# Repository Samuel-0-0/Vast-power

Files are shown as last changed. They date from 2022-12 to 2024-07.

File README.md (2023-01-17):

# Vast Power

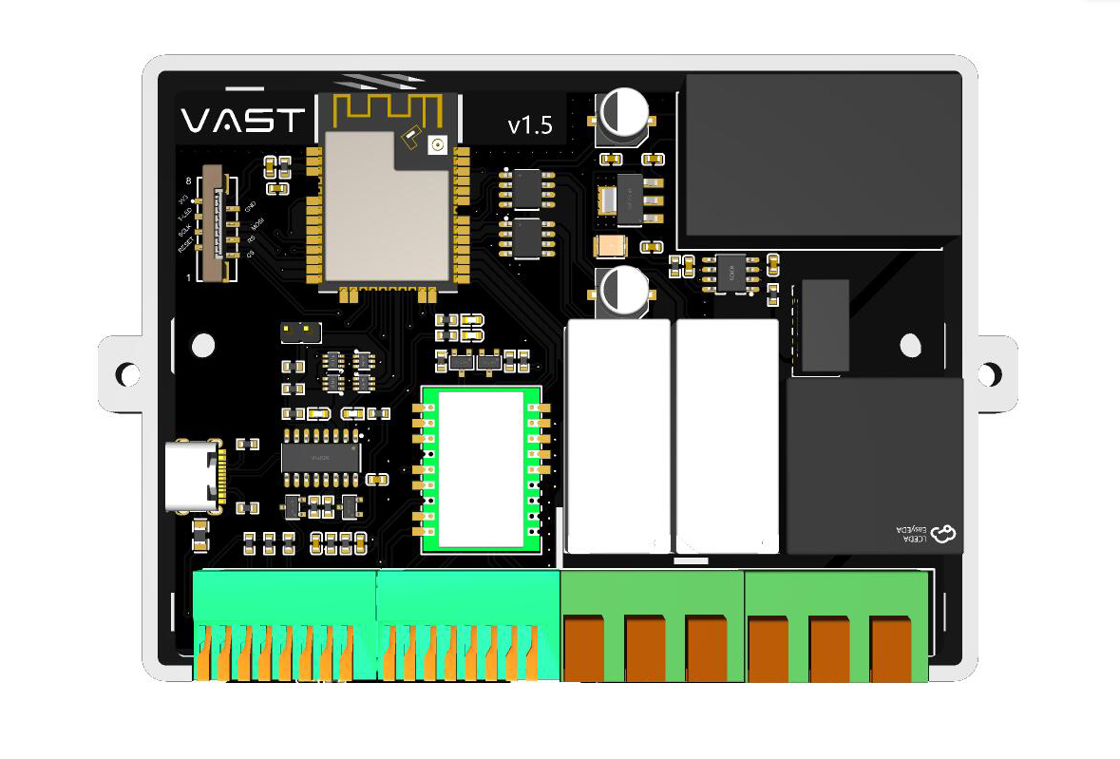
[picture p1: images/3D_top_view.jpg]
Vast-power


本项目原本是因为自己的一些需求而设计，顺便也为将来可能的项目进行前期试水。

## 主要功能

* 可与Home Assistant智能家居系统互联，实现远程控制的目的
* 离线语音控制，可直接控制灯光、继电器等
* 高精度电量统计模块，可精准统计负载耗电量
* 2路16A磁保持继电器
* RGB端口，可用于控制灯光（建议使用100珠及以上SK6812灯带）
* SPI屏幕接口，可外接显示屏自定义显示内容
  * 亦可用于扩展其他SPI设备
* 编码器接口，可外接编码器
  * 亦可拓展为3路输入输出IO（GPIO0受限使用，ESP32启动时不能为低电平）
* 2路ADC接口，或者用于2路IO输入

## 技术依赖

* ESP32程序使用[ESPHome](https://esphome.io/)构建
* 离线语音基于[智能公元](http://www.smartpi.cn/)定制的语音固件

## 接口介绍

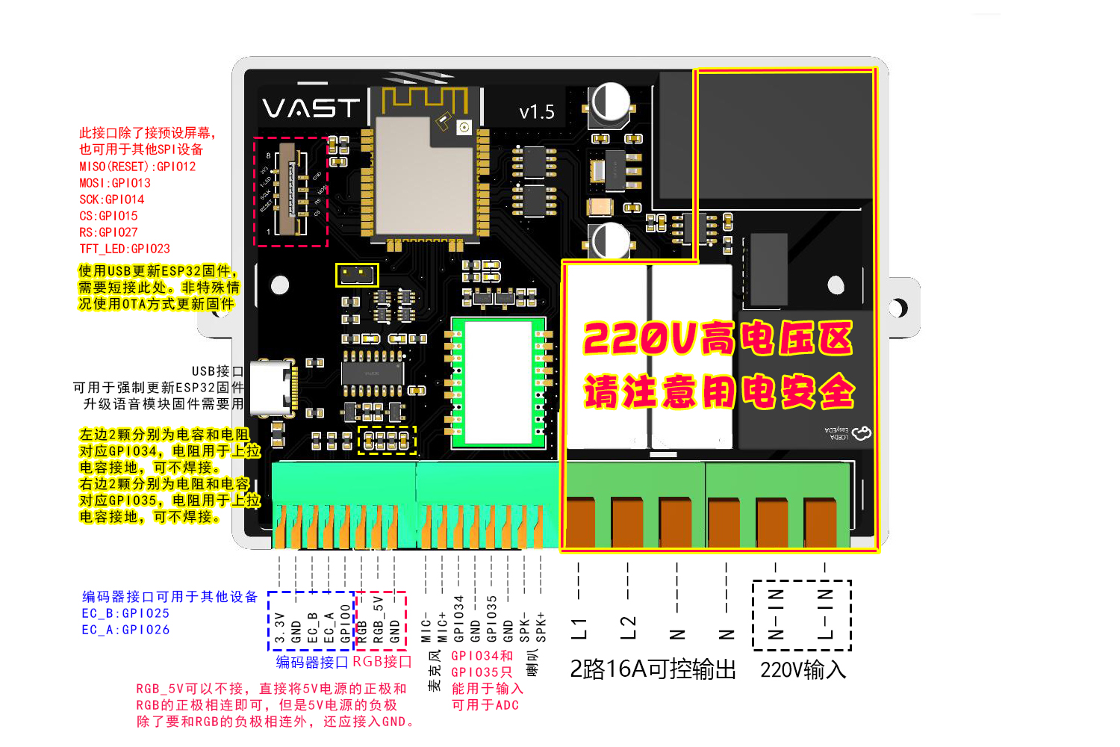
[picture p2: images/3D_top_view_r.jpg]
3D_top_view_r


## PCB

PCB制造文件及相关说明[查看](Gerber/)

## BOM

主要元器件都提供了立创商城元器件编码，可直接导入BOM表购买。

BOM文件 [bom_board_vast-power_2022-12-20](BOM/bom_board_vast-power_2022-12-20.xlsx)

## 3D打印外壳文件

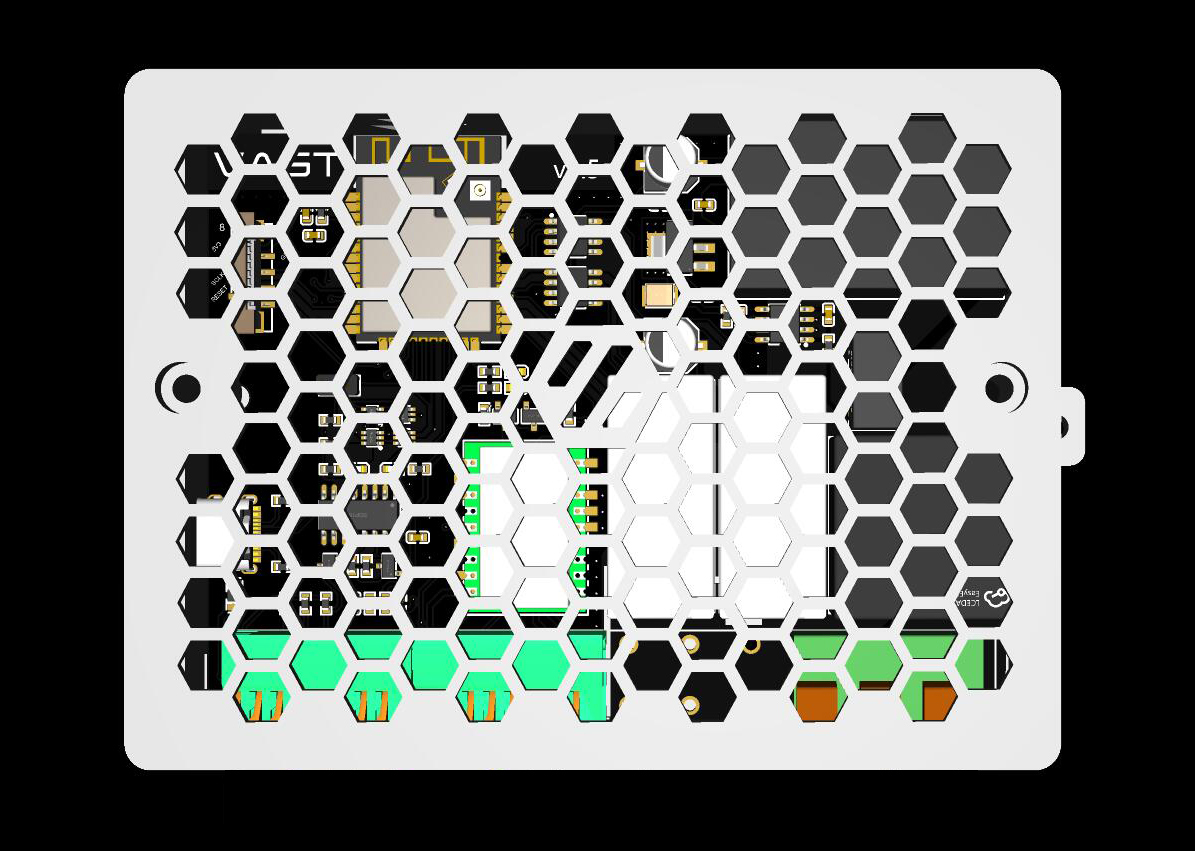
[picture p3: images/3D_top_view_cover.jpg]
3D_top_view_cover


3D打印外壳文件
  * [上盖](STLs/3DShell_vast-power_T.stl) 
  * [下盖](STLs/3DShell_vast-power_B.stl)

## 固件

固件及相关说明[查看](Firmware/)

## IO保护

当需要与打印机主板连接的时候，请确保打印机主板的IO电压为3.3V。若为5V请加保护电路。

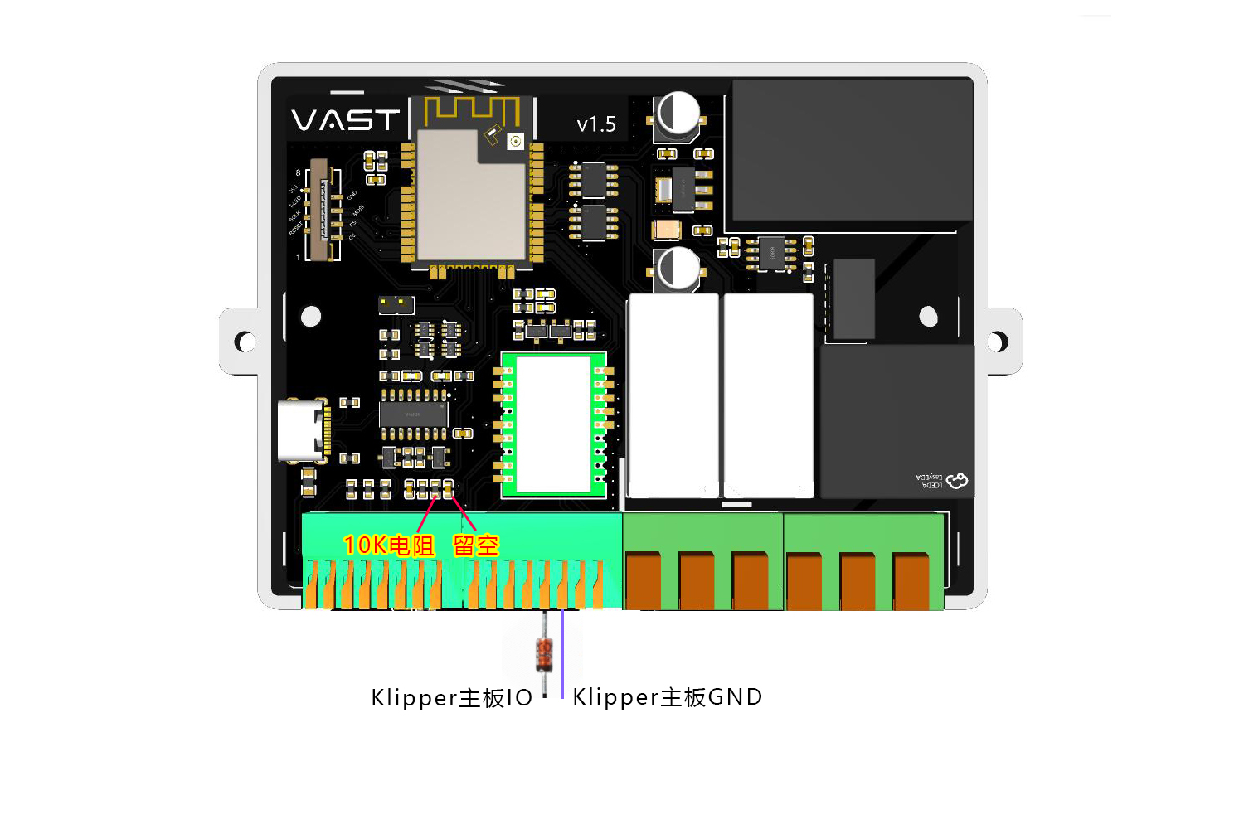
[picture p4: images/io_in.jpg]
io_in


## 显示屏logo文件

Logo文件下载 [PSD](images/voron_design_logo.psd)

## FAQs

待补充

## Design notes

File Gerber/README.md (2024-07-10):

# Vast Power PCB制作

Gerber文件可由嘉立创免费打样

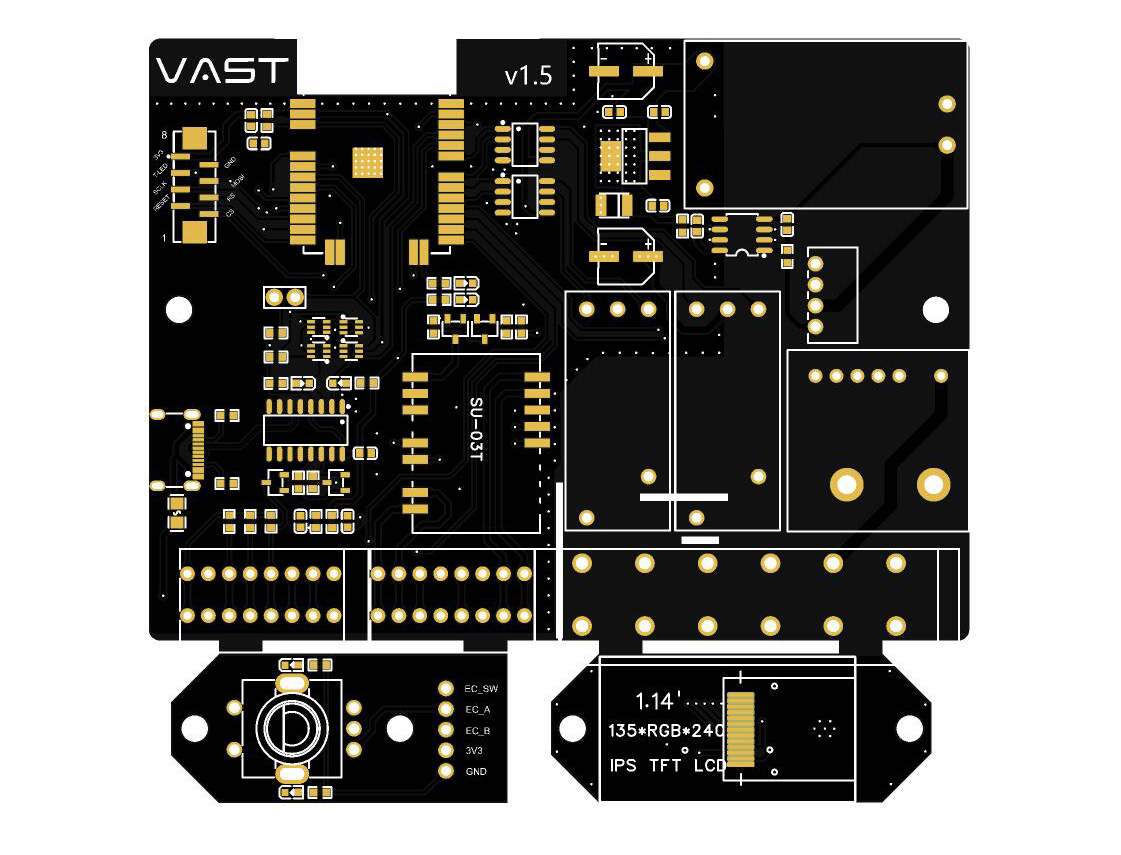
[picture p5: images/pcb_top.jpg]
pcb_top

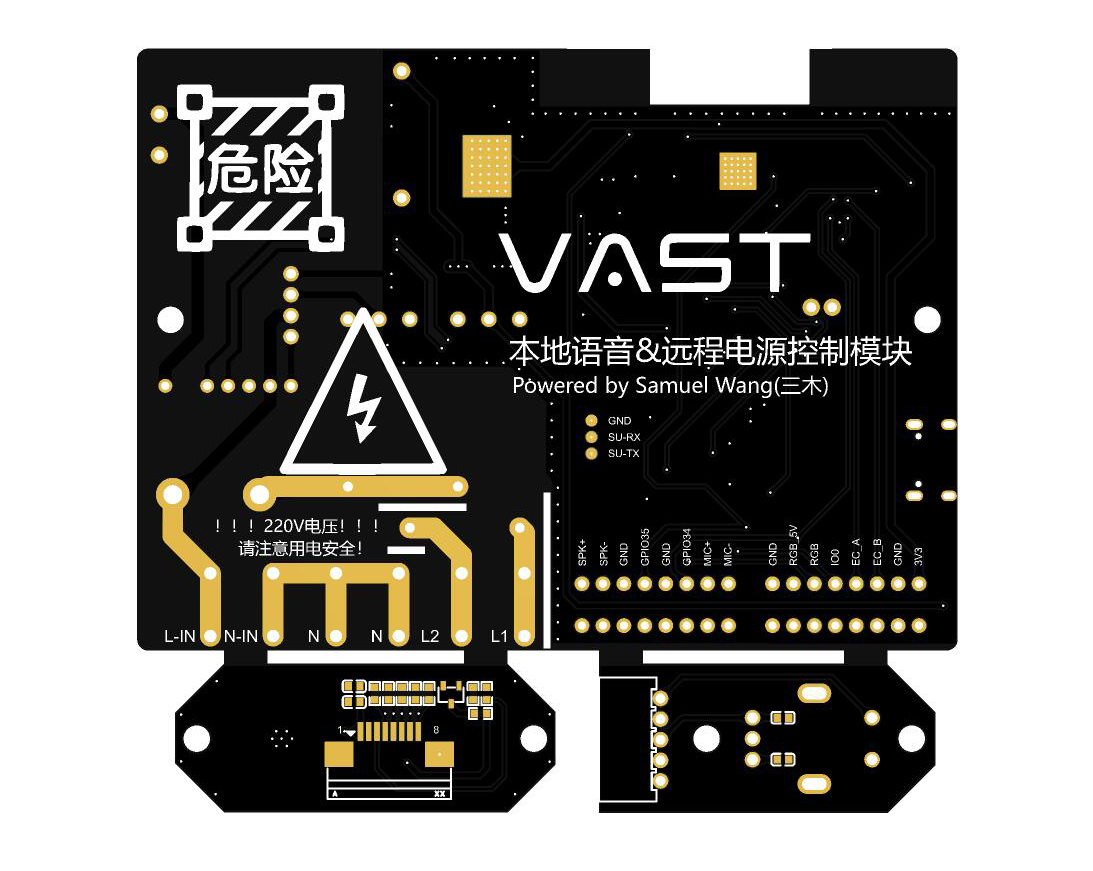
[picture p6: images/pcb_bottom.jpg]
pcb_bottom


## 制造文件

嘉立创制造文件 [Gerber_PCB_vast-power_2022-12-20](Gerber_PCB_vast-power_2022-12-20.zip)

## 焊接说明

1、收到PCB后，先将2块小的附件板切割下来，注意请不要硬掰。

2、下载此焊接辅助文件 [PCB_vast-power_2022-12-20](PCB_vast-power_2022-12-20.html)

3、建议新手分区域焊接测试，先焊接①部分后测试固件是否能正常写入，然后焊接②部分测试继电器是否正常，最后焊接其他部分测试。

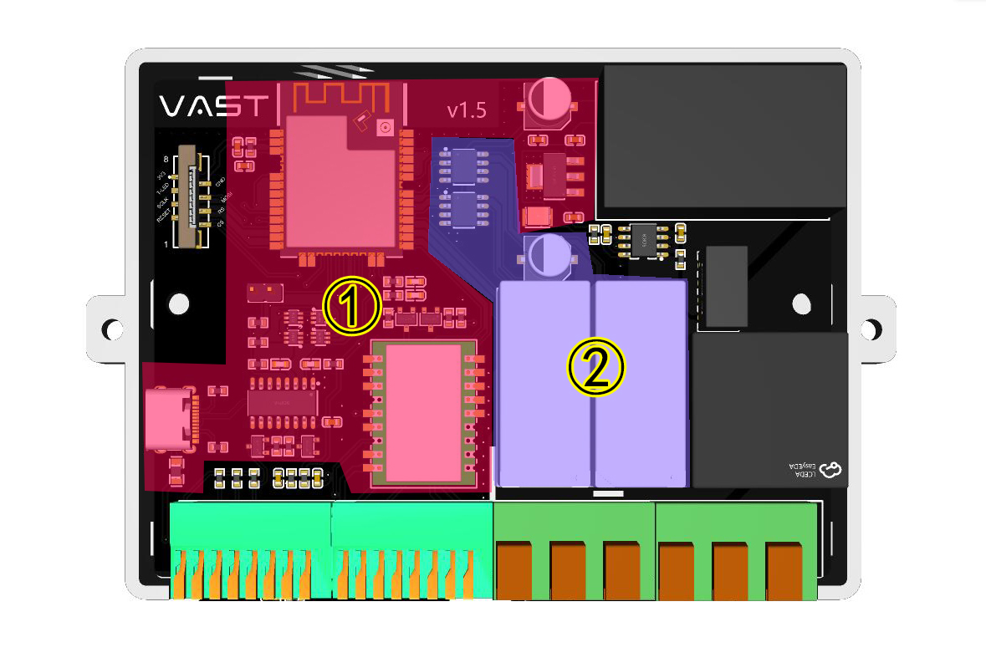
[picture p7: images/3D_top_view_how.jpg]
3D_top_view_how


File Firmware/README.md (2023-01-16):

# Vast Power 固件

目前固件处于测试阶段，并没有完成所有功能的开发与调试。

## 固件下载

* ESP32固件
  * [查看](ESPHome/)
* SU-03T固件
  * 固件 [su_03t_release_update_20221219001_1.1.9](Firmware/SU-03T/su_03t_release_update_20221219001_1.1.9.bin)
  * 烧录软件 [Hummingbird-M-Update-Tool](https://docs.aimachip.com/zh_CN/latest/_static/document/SU-03T/Hummingbird-M-Update-Tool.zip)

## 固件烧录

### ESP32固件烧录方法
初次使用，编译完固件后，下载bin文件。

切断设备供电，短接主板上面2PIN脚，连上USB线，使用[ESPHome-Flasher](https://github.com/esphome/esphome-flasher/releases/tag/1.4.0)烧录。

### SU-03T固件烧录方法
烧录完ESP32固件后设备连上网络，在HomeAssistant里配置-设备与服务-添加集成-ESPHOME。添加完成后，在集成中找到并进入设备。

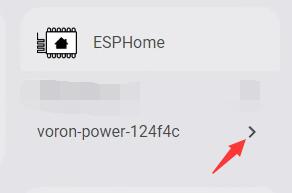
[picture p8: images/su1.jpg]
su1


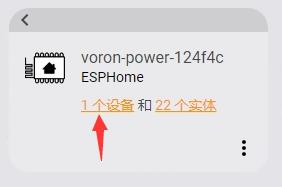
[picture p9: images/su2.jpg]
su2


关闭语音模块电源，打开语音模块烧录

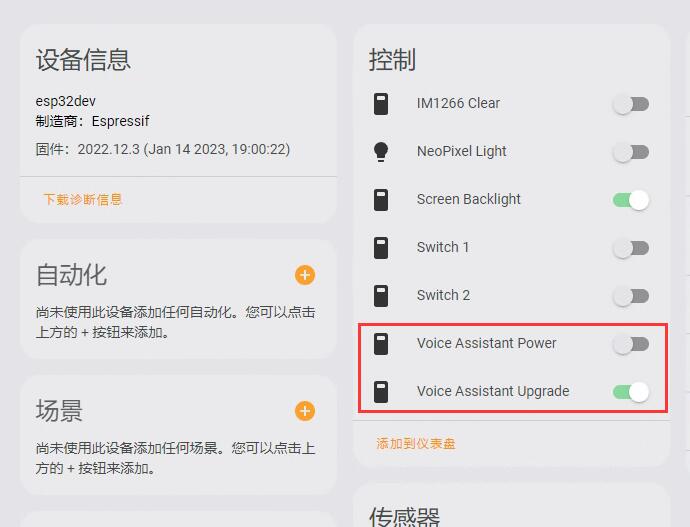
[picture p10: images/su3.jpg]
su3


连上USB线，打开烧录软件，点烧录后出现黄色的COM端口

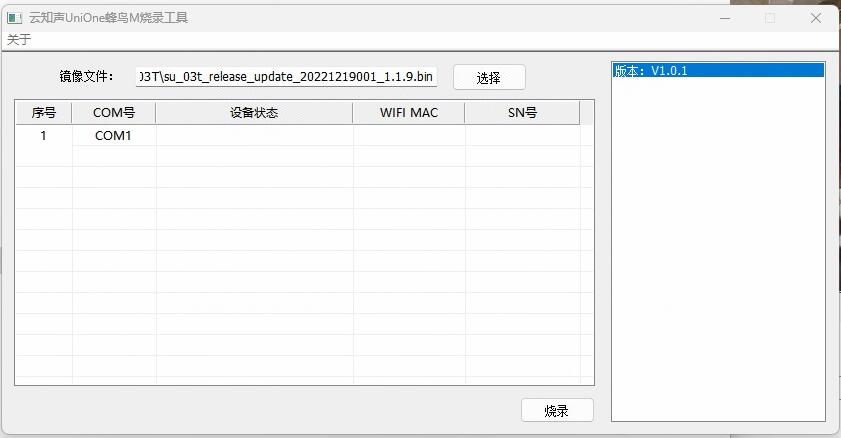
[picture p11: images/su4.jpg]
su4


回到HomeAssistant，打开语音模块电源，此时烧录软件开始工作，等待进度完成即可.

语音固件烧录完成后记得关闭语音模块烧录，否则模块将无法和ESP32通讯。

## ESP32与SU-03T互动

ESP32与SU-03T通过UART接口互动，具体消息内容请参考下方介绍。

* SU-03T发送给ESP32消息内容及意义

| 消息内容 | 代表含义 |
| ----  | ---- |
| 10 11 | 开照明灯 |
| 10 10 | 关照明灯 |
| 10 21 | 开氛围灯 |
| 10 20 | 关氛围灯 |
| 20 11 | 调亮灯光 |
| 20 10 | 调暗灯光 |
| 30 11 | 打开电源 |
| 30 10 | 关闭电源 |
| 40 01 | 暂停打印 |
| 40 10 | 恢复打印 |
| 40 11 | 取消打印 |
| 50 00 | 打印进度 |

* ESP32发送给SU-03T的消息内容及意义

| 消息内容 | 代表含义 |
| ----  | ---- |
| AA 55 01 00 00 00 00 55 AA  | 关闭电源判断，返回打印中 |
| AA 55 02 01 00 00 00 55 AA  | 关闭电源判断，返回未打印 |
| AA 55 03 01 00 00 00 55 AA  | 开始OTA |
| AA 55 04 01 00 00 00 55 AA  | 结束OTA |
| AA 55 05 00 01 02 55 AA  | 打印进度返回，00对应进度百分比数字，01对应剩余小时数字，02对应剩余分钟数字 |

## FAQs

待补充

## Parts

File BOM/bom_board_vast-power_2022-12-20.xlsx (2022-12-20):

No. | PCB位号 | Comment | 封装 | 厂家型号 | 厂家 | 立创商城编号 | 供应商 | 数量 | 单价 | 总价
1 | C1,C3,C4,C6,C7,C8,C11,C12,C15,C16 | 100nF | C0603 | FN18X104K160PSG | PSA(信昌电陶) | C235729 | LCSC | 10 | 0.030615 | 0.30615 | 可用X7R同规格替代
2 | C2,C5,C10,C14 | 10uF | C0603 | CL10A106KP8NNNC | SAMSUNG(三星) | C19702 | LCSC | 4 | 0.039434 | 0.157736 | 可用X7R同规格替代，当GPIO35/GPIO35用于IO输入时，可不焊接
3 | C9,C17 | 220uF | CAP-SMD_BD6.3-L6.6-W6.6-FD | VD1C221ME077000CE0 | HUAWEI(华威集团) | C189266 | LCSC | 2 | 0.443113 | 0.886226
4 | C13 | 10uF | CAP-SMD_L3.2-W2.8 | TAJB106K016RNJ | Kyocera AVX | C7193 | LCSC | 1 | 0.642535 | 0.642535
5 | CN6 | XH-5AW | CONN-TH_XH2.54-5AW | XH-5AW | BOOMELE(博穆精密) | C24023 | LCSC | 1 | 0.105975 | 0.105975
6 | CN7 | TFT1.14 |  |  | 深圳华迪创显科技 |  | 淘宝 | 1 | 8 | 8 | 运费10，非必须
7 | CN8,CN9 | DB141R-2.54-8P | CONN-TH_8P-P2.54_DIBO_DB141R-2.54-8P | DB141R-2.54-8P | DIBO(地博电气) | C2898760 | LCSC | 2 | 3.58 | 7.16
8 | CN10 | DB142R-7.62-6P | CONN-TH_6P-P7.62_DIBO_DB142R-7.62-6P | DB142R-7.62-6P | DIBO(地博电气) | C2898732 | LCSC | 1 | 3.27 | 3.27
9 | F1 | SMD0805-075 | F0805 | SMD0805-075 | 台湾陆海 | C70060 | LCSC | 1 | 0.308501 | 0.308501
10 | FPC1 | F1003-ZV-08-25T-R | FPC-SMD_F1003-ZV-08-25T-R | F1003-ZV-08-25T-R | XFCN(台湾兴飞) | C481413 | LCSC | 1 | 0.739482 | 0.739482
11 | FPC2 | F1001-T-08-25T-R | FPC-SMD_8P-P1.00_L5.5-W15.0 | F1001-T-08-25T-R | XFCN(台湾兴飞) | C481253 | LCSC | 1 | 0.636777 | 0.636777
12 | H1 | PZ254V-11-02P | HDR-TH_2P-P2.54-V-M | PZ254V-11-02P | XFCN(兴飞) | C492401 | LCSC | 1 | 0.097357 | 0.097357
13 | LED1,LED2,LED3,LED4,LED5,LED6 | 19-217/BHW-ZL2N1QY/3T | LED0603-RD_BLUE | 19-217/BHW-ZL2N1QY/3T | EVERLIGHT(亿光) | C264472 | LCSC | 6 | 0.1768 | 1.0608 | 0603的LED，自由选择颜色、品牌
14 | Q1 | WST3401A | SOT-23-3_L2.9-W1.6-P1.90-LS2.8-BR | WST3401A | WINSOK微硕 | C2758407 | LCSC | 1 | 0.278131 | 0.278131
15 | Q2 | WST3400A | SOT-23-3_L2.9-W1.6-P1.90-LS2.8-BR | WST3400A | WINSOK微硕 | C2758406 | LCSC | 1 | 0.285625 | 0.285625
16 | Q3,Q4,Q8 | S8050 J3Y | SOT-23-3_L3.0-W1.7-P0.95-LS2.9-BR | S8050 J3Y | CJ(江苏长电/长晶) | C2146 | LCSC | 3 | 0.092812 | 0.278436
17 | Q6,Q7 | ULN2001D | SOP-8_L4.9-W3.9-P1.27-LS6.0-BL | ULN2001D | Mixic(中科芯亿达) | C108905 | LCSC | 2 | 0.671561 | 1.343122
18 | R1,R4,R5,R7,R9,R11,R17,R18,R19,R20,R21,R22,R23,R24 | 10kΩ | R0603 | 0603WAJ0103T5E | UNI-ROYAL(厚声) | C15401 | LCSC | 14 | 0.00653 | 0.09142
19 | R2,R3,R12,R15,R32 | 100kΩ | R0603 | 0603WAF1003T5E | UNI-ROYAL(厚声) | C25803 | LCSC | 5 | 0.006813 | 0.034065 | 当GPIO34/GPIO35用于IO输入时R12/R15用10K
20 | R10,R16 | 5.1kΩ | R0603 | 0603WAF5101T5E | UNI-ROYAL(厚声) | C23186 | LCSC | 2 | 0.005976 | 0.011952
21 | R6,R8,R13,R14,R29,R33 | 330Ω | R0603 | 0603WAF3300T5E | UNI-ROYAL(厚声) | C23138 | LCSC | 4 | 0.005999 | 0.023996 | 可用1kΩ代替
23 | R27,R28 | 100Ω | R0603 | 0603WAF1000T5E | UNI-ROYAL(厚声) | C22775 | LCSC | 2 | 0.005659 | 0.011318
24 | R30 | 10Ω | R0603 | 0603WAF100JT5E | UNI-ROYAL(厚声) | C22859 | LCSC | 1 | 0.005856 | 0.005856
25 | R31 | 1kΩ | R0603 | 0603WAF1001T5E | UNI-ROYAL(厚声) | C21190 | LCSC | 1 | 0.002797 | 0.002797
26 | SU1 | SU-03T | COMM-SMD_18P-L21.0-W15.0-P2.00 | SU-03T | MACHINE INTELLIGENCE(机芯智能) | C879203 | LCSC | 1 | 15.21 | 15.21 | 淘宝9.5 运费6 可申请1个样品
27 | SW1 | EC11E18244AU | SW-TH_EC11XXXXXXXX | EC11E18244AU | ALPSALPINE(阿尔卑斯阿尔派) | C202365 | LCSC | 1 | 11.99 | 11.99 | 非必须
28 | U1 | ESP32-S | WIRELM-SMD_ESP32-S | ESP32-S | Ai-Thinker(安信可) | C277944 | LCSC | 1 | 23.71 | 23.71
29 | U2,U3,U4,U5 | SGM3157 | SC-70-6_L2.2-W1.3-P0.65-LS2.2-BR | SGM3157 | UMW(友台半导体) | C394901 | LCSC | 4 | 0.410262 | 1.641048
30 | U7 | CH340C | SOP-16_L10.0-W3.9-P1.27-LS6.0-BL | CH340C | WCH(南京沁恒) | C84681 | LCSC | 1 | 2.86 | 2.86
31 | U8 | B0505S-W5 | PWRM-TH_BXXXXS-W5 | B0505S-W5 | NYBOXING(尼博星) | C3345179 | LCSC | 1 | 8.68 | 8.68 | HI-LINK有同型号产品
32 | U10 | HLK-PM01 | PWRM-TH_HLK-PM01 | HLK-PM01 | HI-LINK(海凌科) | C209903 | LCSC | 1 | 18.94 | 18.94
33 | U11 | IM1266 | PWRM-TH_IM1266 | IM1266 | IRdopto(艾锐达) | C471615 | LCSC | 1 | 34.24 | 34.24 | 淘宝22.7 运费10
34 | U13 | AMS1117-3.3 | SOT-223-3_L6.5-W3.4-P2.30-LS7.0-BR | AMS1117-3.3 | 美国AMS | C6186 | LCSC | 1 | 0.9483 | 0.9483
35 | U15 | π121U31 | SOIC-8_L5.0-W4.0-P1.27-LS6.0-BL | π121U31 | 2Pai Semi(荣湃) | C471589 | LCSC | 1 | 1.7603 | 1.7603
36 | U16,U17 | HFE20-1/5-1HST-L2 | RELAY-TH_HONGFA_HFE20-1-X-1HST-L2 | HFE20-1/5-1HST-L2 | 宏发 |  | 淘宝 | 2 | 5 | 10 | 运费4 满10个包邮
37 | USBC1 | TYPE-C-31-M-12 | USB-C_SMD-TYPE-C-31-M-12 | TYPE-C-31-M-12 | 韩国韩荣 | C165948 | LCSC | 1 | 1.4303 | 1.4303
 |  |  |  |  |  |  |  |  |  | 157.148205

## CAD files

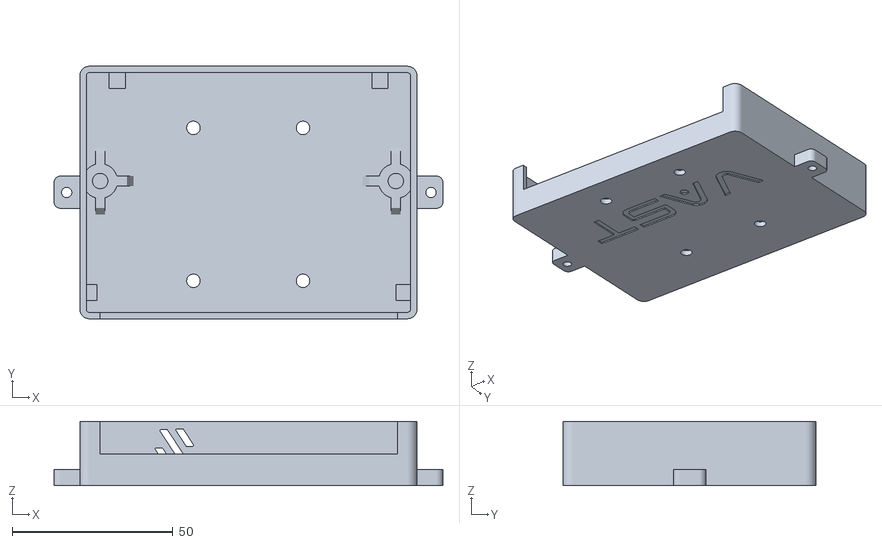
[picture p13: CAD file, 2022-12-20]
STLs/3DShell_vast-power_B.stl
120.8 x 78.5 x 20.0

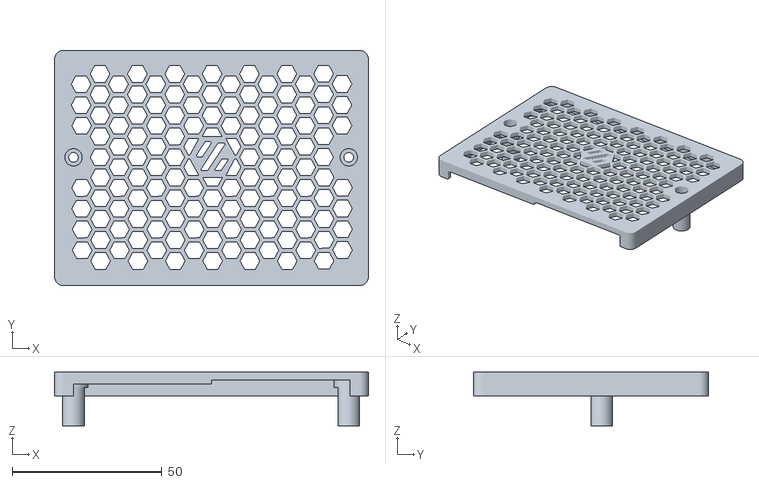
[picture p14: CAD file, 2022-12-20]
STLs/3DShell_vast-power_T.stl
104.7 x 78.5 x 18.0

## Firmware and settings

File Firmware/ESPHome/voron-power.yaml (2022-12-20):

# ============================================================================================
#  secrets.yaml
#
#  wifi_ssid: 'ssid'                    # WiFi_SSID名称
#  wifi_password: '12345678'            # WiFi密码
#  wifi_password_AP: '12345678'         # AP模式密码
#  wifi_fast_connect: 'false'           # 如果SSID是隐藏的，设置为true
#  wifi_reboot_timeout: 0s              # WiFi离线多久后重启设备，秒s/分钟min/小时h，不需要此功能设置为0s
#  wifi_gateway: '192.168.88.1'         # 网关
#  wifi_subnet: '255.255.255.0'         # 子网掩码
#  wifi_dns1: '192.168.88.1'            # 主DNS
#  ota_password: '12345678'             # OTA密码
#  api_password: '12345678'             # API密码
#  api_reboot_timeout: 0s               # 与Home Assistant失去连接多久后重启设备，秒s/分钟min/小时h，不需要此功能设置为0s
#  mqtt_host: '192.168.88.115'          # MQTT代理服务器IP地址
#  mqtt_port: '1883'                    # MQTT代理服务器端口
#  mqtt_username: ''                    # MQTT代理服务器用户名
#  mqtt_password: ''                    # MQTT代理服务器密码
#  mqtt_reboot_timeout: 0s              # 与MQTT服务端失去连接多久后重启设备，秒s/分钟min/小时h，不需要此功能设置为0s
# ============================================================================================

substitutions:
  wifi_ip_voron_power: '192.168.88.192'                       # 静态IP地址
  moonraker_api: 'http://192.168.88.173:7125/printer/info'    # moonraker api地址
  #moonraker_api: 'http://192.168.88.11:1880/voron'

esphome:
  name: voron-power
  name_add_mac_suffix: True         # 在名字后面添加mac后缀
  includes:
    - su_03t.h                      # 添加自定义的传感器
  # 设置新的OTA密码
#  on_boot:
#    - lambda: |-
#        id(voron_ota).set_auth_password("New password");

esp32:
  board: esp32dev                   # ESP32-S模组默认用nodemcu-32s，端口全引出
  variant: esp32                    # 不同版本，esp32, esp32s2, esp32s3, esp32c3, esp32h2
#  framework:
#    type: esp-idf
#    version: recommended
    # Custom sdkconfig options
#    sdkconfig_options:
#      CONFIG_COMPILER_OPTIMIZATION_SIZE: y
    # Advanced tweaking options
#    advanced:
#      ignore_efuse_mac_crc: false

# 调试模式，可以在ESPHOME后台显示日志信息
debug:

# 打印日志
logger:
  baud_rate: 0            # 默认115200，设置0关闭UART日志输出
  level: VERBOSE          # 可选等级 NONE, ERROR, WARN, INFO, DEBUG, VERBOSE, VERY_VERBOSE
##  logs:
##    mqtt.component: DEBUG
##    mqtt.client: ERROR
##  hardware_uart: UART0
  #→ UART0 - TX: GPIO1, RX: GPIO3
  #→ The ESP8266 UART0 can also be ‘swapped’ to TX/RX on the CTS/RTS pins, 
  #→ if you need to use GPIO1 and GPIO3 for something else.
  #→ UART0_SWAP - TX: GPIO15, RX: GPIO13 (Only on ESP8266)
  #→ UART1 - TX: GPIO2, RX: None (Only on ESP8266)
  #→ UART1 - TX: GPIO9, RX: GPIO10 (Only on ESP32)
  #→ UART2 - TX: GPIO16, RX: GPIO17 (Only on ESP32)

# 状态灯
status_led:
  pin: GPIO2

###  Home Assistant API 和 MQTT 只选1个开启  ###

# 使用Home Assistant API
api:
  reboot_timeout: !secret api_reboot_timeout
  encryption:
    key: !secret api_encryption_key

# 使用MQTT
##mqtt:
##  broker: !secret mqtt_host
##  username: !secret mqtt_username
##  password: !secret mqtt_password
##  reboot_timeout: !secret mqtt_reboot_timeout
##  id: mqtt_client

###  Home Assistant API 和 MQTT 只选1个开启  ###

# 使用WEB API接入    https://esphome.io/web-api/index.html
##web_server:
##  port: 80

# 在线更新
ota:
  id: voron_ota
  password: !secret ota_password
  on_begin:
    then:
      - uart.write:
          id: su_uart
          data: [0xAA, 0x55, 0x03, 0x01, 0x00, 0x00, 0x00, 0x55, 0xAA] #返回正在OTA
  on_end:
    then:
      - uart.write:
          id: su_uart
          data: [0xAA, 0x55, 0x04, 0x01, 0x00, 0x00, 0x00, 0x55, 0xAA] #返回OTA已完成

# WIFI
wifi:
  ssid: !secret wifi_ssid
  password: !secret wifi_password
  reboot_timeout: !secret wifi_reboot_timeout
  fast_connect: !secret wifi_fast_connect
  # 设置固定IP地址
  manual_ip:
    static_ip: $wifi_ip_voron_power
    gateway: !secret wifi_gateway
    subnet: !secret wifi_subnet
    dns1: !secret wifi_dns1

  # 无法连接wifi时开启AP模式(captive portal)，如果不启用webserver则没必要开启此配置
##  ap:
##    ssid: "Voron-Power Fallback Hotspot"
##    password: !secret wifi_password_AP

# AP模式
##captive_portal:

# 串口
uart:
  # 语音模块
  - id: su_uart
    tx_pin: GPIO1
    rx_pin: GPIO3
    baud_rate: 9600
    #data_bits: 8
    #parity: NONE
    #stop_bits: 1
    debug:
      #direction: RX
      sequence:
        - lambda: UARTDebug::log_hex(direction, bytes, ':');
  # 电量模块
  - id: im1266_uart
    tx_pin: GPIO17
    rx_pin: GPIO16
    baud_rate: 4800
    data_bits: 8
    parity: NONE
    stop_bits: 1
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

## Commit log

2022-12-20 新增固件说明
2023-01-09 更新说明
